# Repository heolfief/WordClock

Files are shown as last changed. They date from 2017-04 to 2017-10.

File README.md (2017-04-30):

# 8x8 Dot Matrix Word Clock
This is an AVR based mini word clock featuring:
* Real Time Clock (DS3231)
* LiPo battery with integrated USB charging circuit
* low battery sensing

The unit is composed of two stacked PCB and one 8x8 dot-matrix display module.

The Hardware folder is composed of Autodesk Eagle CAD files (schematics and PCB) and of Bill Of Materials.

The Software folder is composed of Atmel Studio 7.0 project files, including libraries and hex file.

The I2C-master-lib is from user g4lvanix on Github ([github.com/g4lvanix/I2C-master-lib](http://github.com/g4lvanix/I2C-master-lib)). However, he does not include any licence in his repository therefore all rights for this library belongs to him.
All other libraries included are under the licence descibed in the LICENCE.md file.

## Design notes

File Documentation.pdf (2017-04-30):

2017

# 8X8 DOT MATRIX WORD CLOCK

### This is an AVR based mini word clock featuring: - Real Time Clock (DS3231) - LiPo battery with integrated USB charging circuit (MCP73831) - low battery sensing

The unit is composed of two stacked PCB and one 8x8 dot-matrix display module.

# Heol Fief

github.com/heolfief

Heol Fief
github.com/heolfief | 1

## Table of Contents

## 1. 8x8 Dot matrix letters and MCU PORTs configuration

## a. Letters display configuration

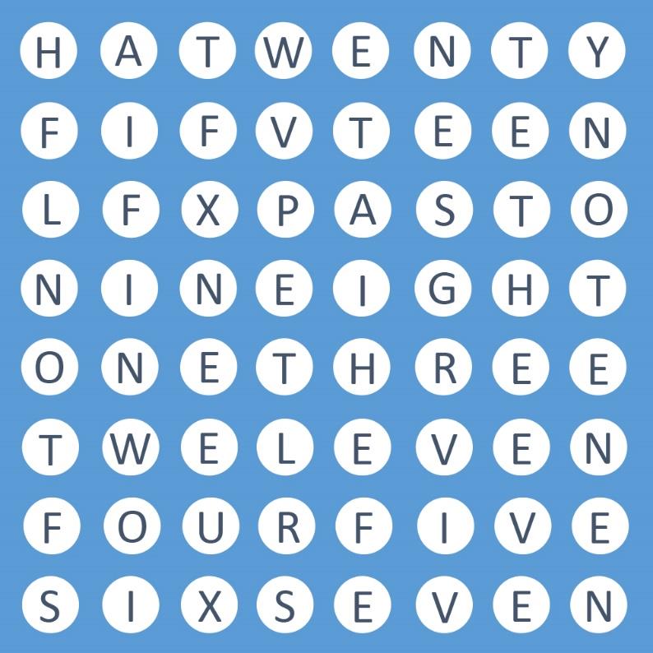
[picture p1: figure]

Figure 1 is the matrix configuration for displaying time in the following format:

Minutes | Link | Hours
| PAST | ONE
FIVE | TO | TWO
TEN | | THREE
FIFTEEN | | FOUR
TWENTY | | FIVE
TWENTY FIVE | | SIX
HALF | | SEVEN
EIGHT
NINE
TEN
ELEVEN
TWELVE

e.g.: HALF PAST TEN (10:30) or TEN TO THREE (02:50).

Note that a.m. and p.m. are considered the same.

FIGURE 1: LETTERS CONFIGURATION

## b. LED matrix pinout

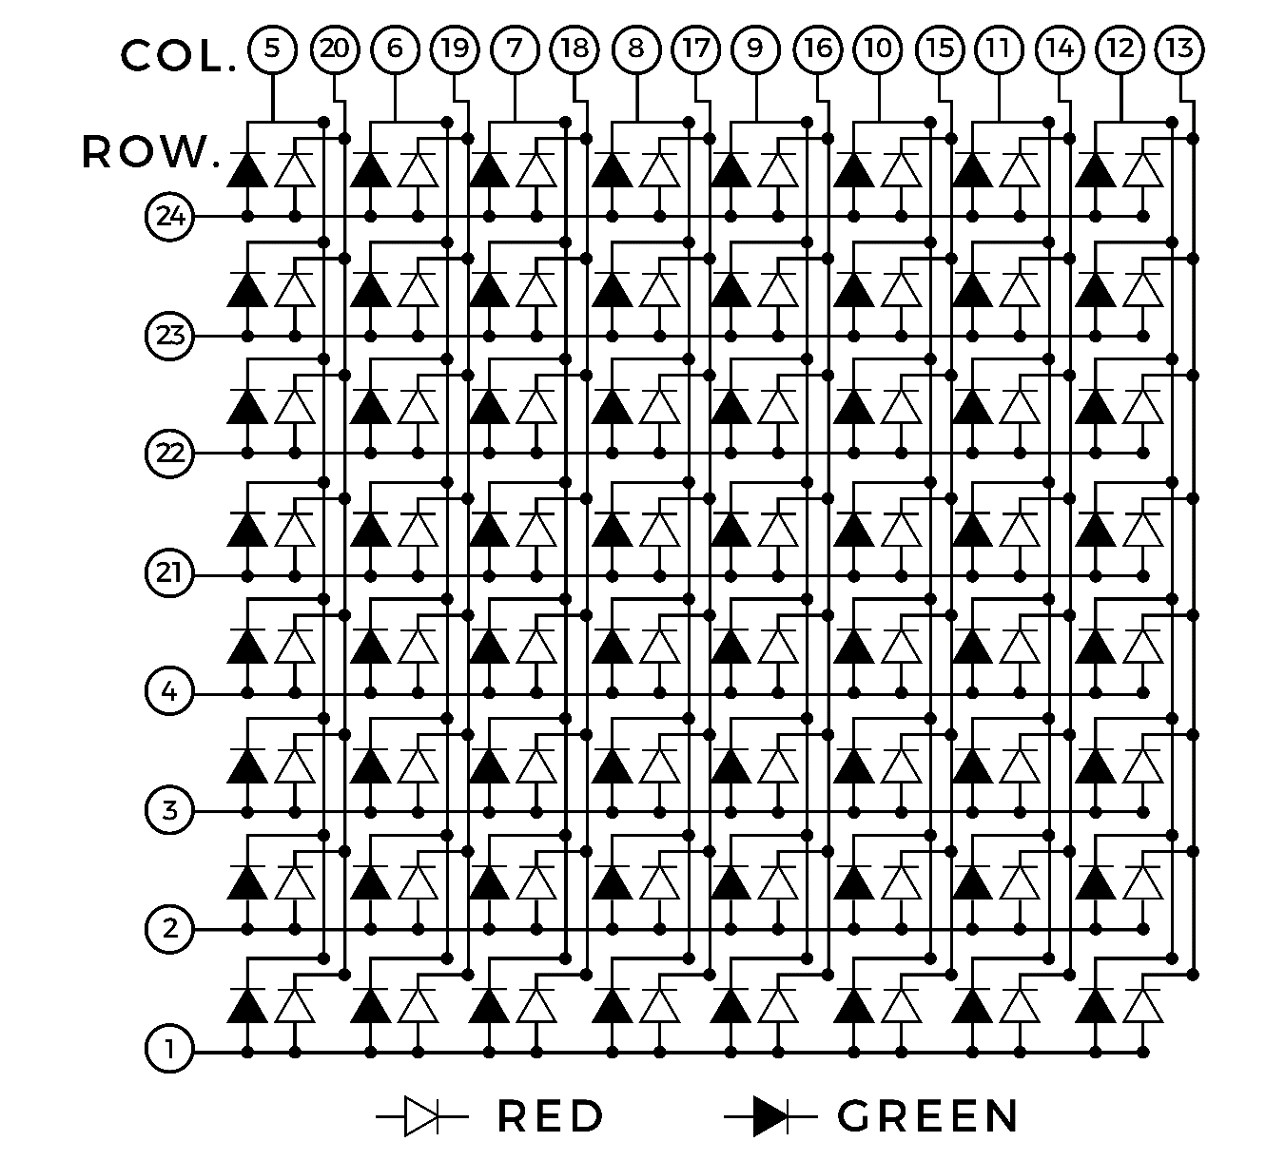
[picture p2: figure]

This is the pinout diagram of the “1588ABEG-5” 8x8 dot matrix display.
In this design, only the green LED are used. Therefore, red LED cathodes (pins 20, 19, 18, 17, 16, 15, 14 and 13) are connected to VCC (LEDs off).

FIGURE 2: LED MATRIX PINOUT

## c. MCU ports configuration

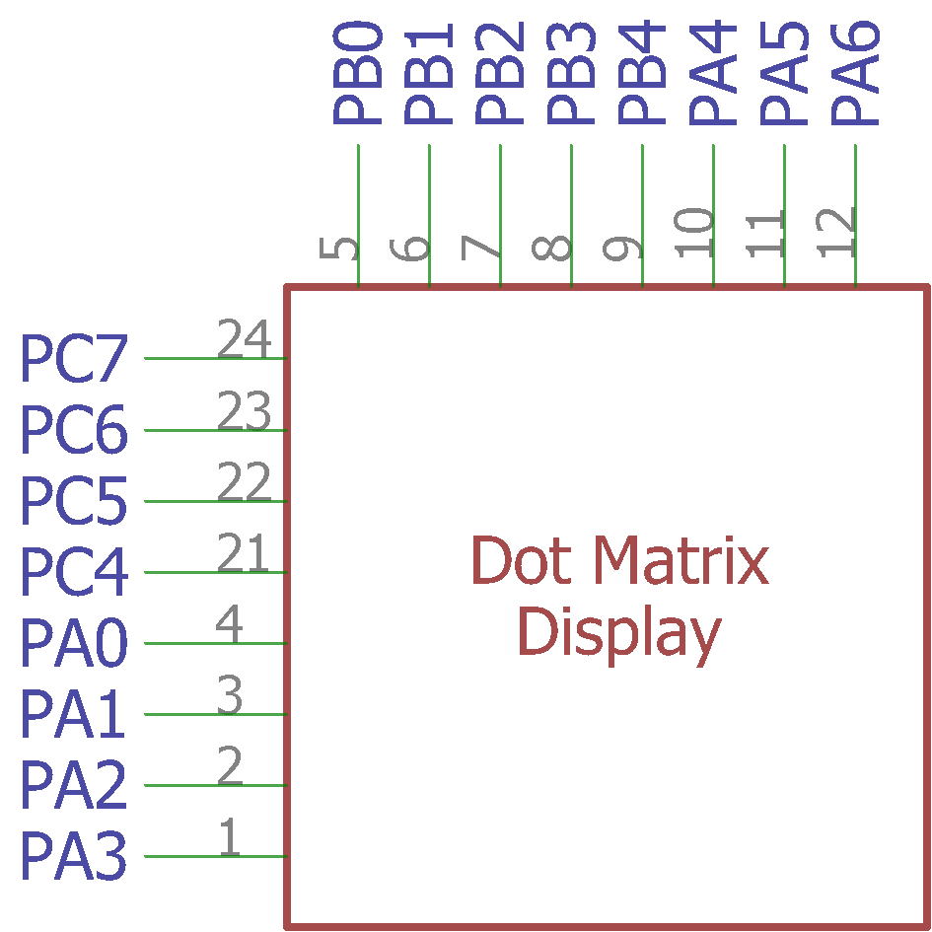
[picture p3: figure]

: Matrix pinout

: MCU pinout

Figure 3 is the connection diagram between the AVR pins and the Matrix pins. ‘PXy’ stands for PORTX pin y.

FIGURE 3: MCU TO MATRIX CONNECTIONS

## 2. Battery voltage sensing calculations

## a. Voltage divider:

LiPo battery voltage needs to be stepped down from 4.3v (maximum value) to 3.3v to be read properly by the MCU running at 3.3v.

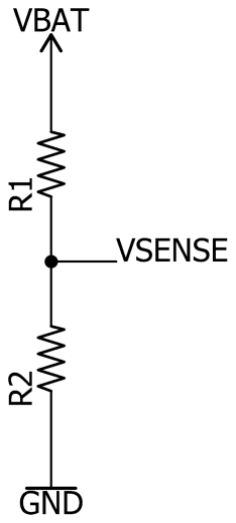
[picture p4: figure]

Vsense =

R2
R1+R2

Vbat

⇔ R2 = −

Vsense

Vsense+Vbat

R1

⇔ R2 = −

3.3
3.3+4.3

R1
⇔ R2 = 3.3R1

For R₁ = 100kΩ, R₂ =330kΩ.

By choosing such high resistor values, we limit the current going from Vbat to GND, lim-iting battery discharge.

Here, Iwasted =

Vbat
R1+R2

=

3.7
430

k = 8.6µA which won't discharge the battery too quickly.

By taking the formula in reverse, we get: Vsense = 330 k 330k+100k
Vbat =

33
43

Vbatwhich

means for example if the MCU mesures 2.5v, the battery voltage Vbat equals 2.5

33
43

⁄ = 2.5

43
33

= 3.26v.

## a. Sensing voltage:

The ATmega32A has a 10 bit DAC which means it can measure voltages from GND (0v) to AREF (3,3v in this case), with a 10 bits resolution (0 to 1023).

To get the battery voltage from the 10 bit number returned by the ADC conversion, we need to apply this formula: Vbat =

3.3ADCvalue
1023

×

43
33

In C, it is done by executing this line of code: float voltage = adcvalue*3.3*43/1023/33;

FIGURE 4: BATTERY
SENSING VOLTAGE
DIVIDER

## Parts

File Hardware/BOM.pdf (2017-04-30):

Word Clock BOM

Part | Value | Description | Package
IC1 | ATMEGA32-A | MICROCONTROLLER | TQFP44
IC2 | HT7333 | Low Dropout voltage regulator 3.3v | SOT-89
IC3 | DS3231 | Real Time Clock | SOIC-16W
IC4 | MCP73831 | MCP73831T Li-Ion, Li-Po Controller | SOT23-5
R1, R10 | 10k | Resistor | 0805
R2, R7 | 330 | Resistor | 0805
R3 | 2k | Resistor | 0805
R4 | 100k | Resistor | 0805
R5 | 330k | Resistor | 0805
R6 | 390 | Resistor | 0805
R8, R9 | 4,7k | Resistor | 0805
RN1, RN2 | 390 | Array Chip Resistor | 0603-ARC
C1, C2, C4, C7, C8 | 0.1u | Capacitor | 0805
C3 | 47u | Tantalum Capacitor | D / 7343
C5, C6 | 4.7u | Capacitor | 0805
LED1 | Green | LED | 1206
LED2 | Red | LED | 1206
LED3 | 1588ABEG-5_8X8-LED_MATRIX | 8x8 dot matrix display, green and red | 1588ABEG-5
J1 | LiPo battery connector | 0.1 inch spaced header connections | MOLEX-1X2
J2, J3, J4, J6, J7, J8 | | 0.1 inch spaced header connections | 1X02
J5, J9 | | 0.1 inch spaced header connection | 1X01
J10 | USB MICRO B | USB connector SMD package | USB-MICRO B
| | | SMD
JP1 | 6 pin AVR ICSP right angle connector | 0.1 inch spaced header connections | 2X03 /90°
S1 | Momentary button 6.mm THT | Momentary Switch (Pushbutton) - SPST | 6.0MM

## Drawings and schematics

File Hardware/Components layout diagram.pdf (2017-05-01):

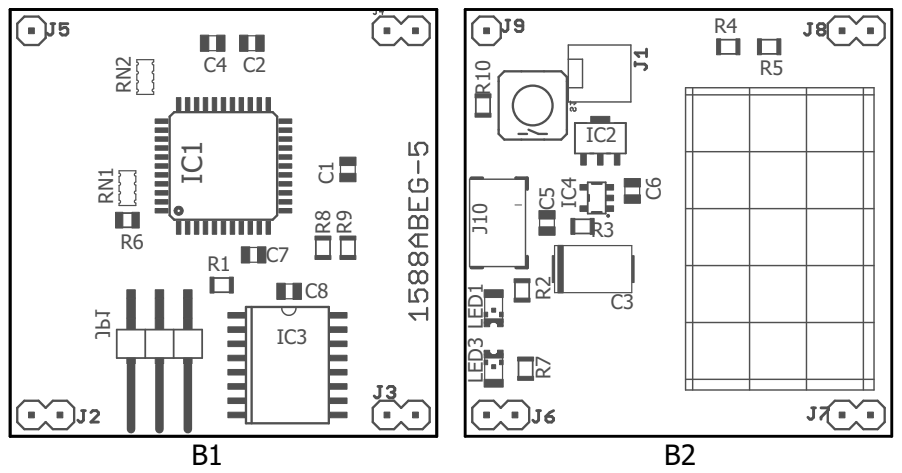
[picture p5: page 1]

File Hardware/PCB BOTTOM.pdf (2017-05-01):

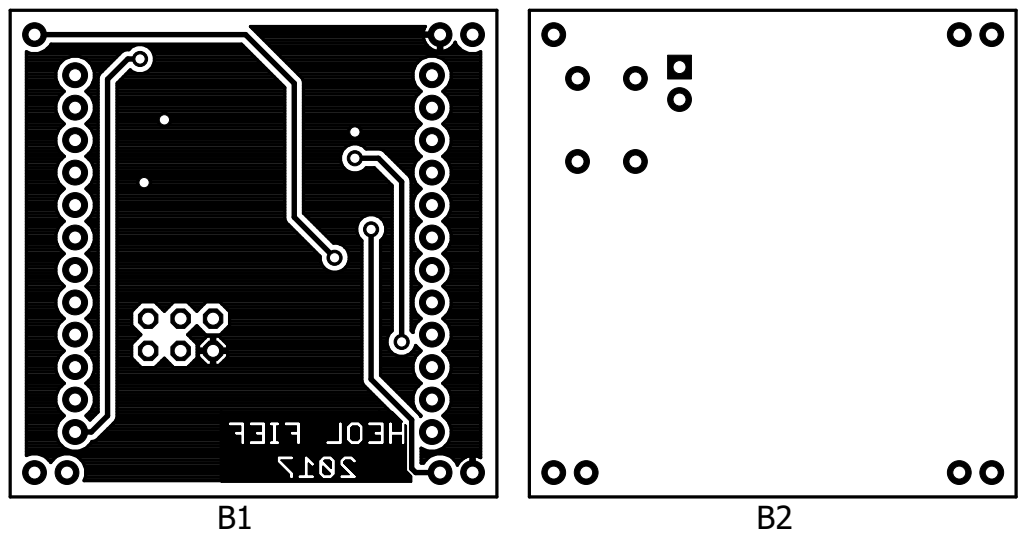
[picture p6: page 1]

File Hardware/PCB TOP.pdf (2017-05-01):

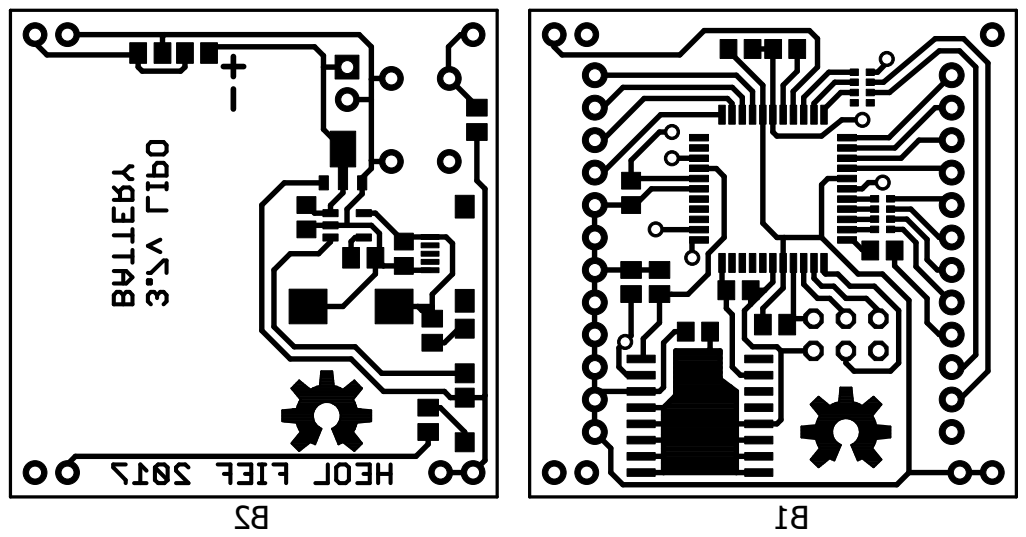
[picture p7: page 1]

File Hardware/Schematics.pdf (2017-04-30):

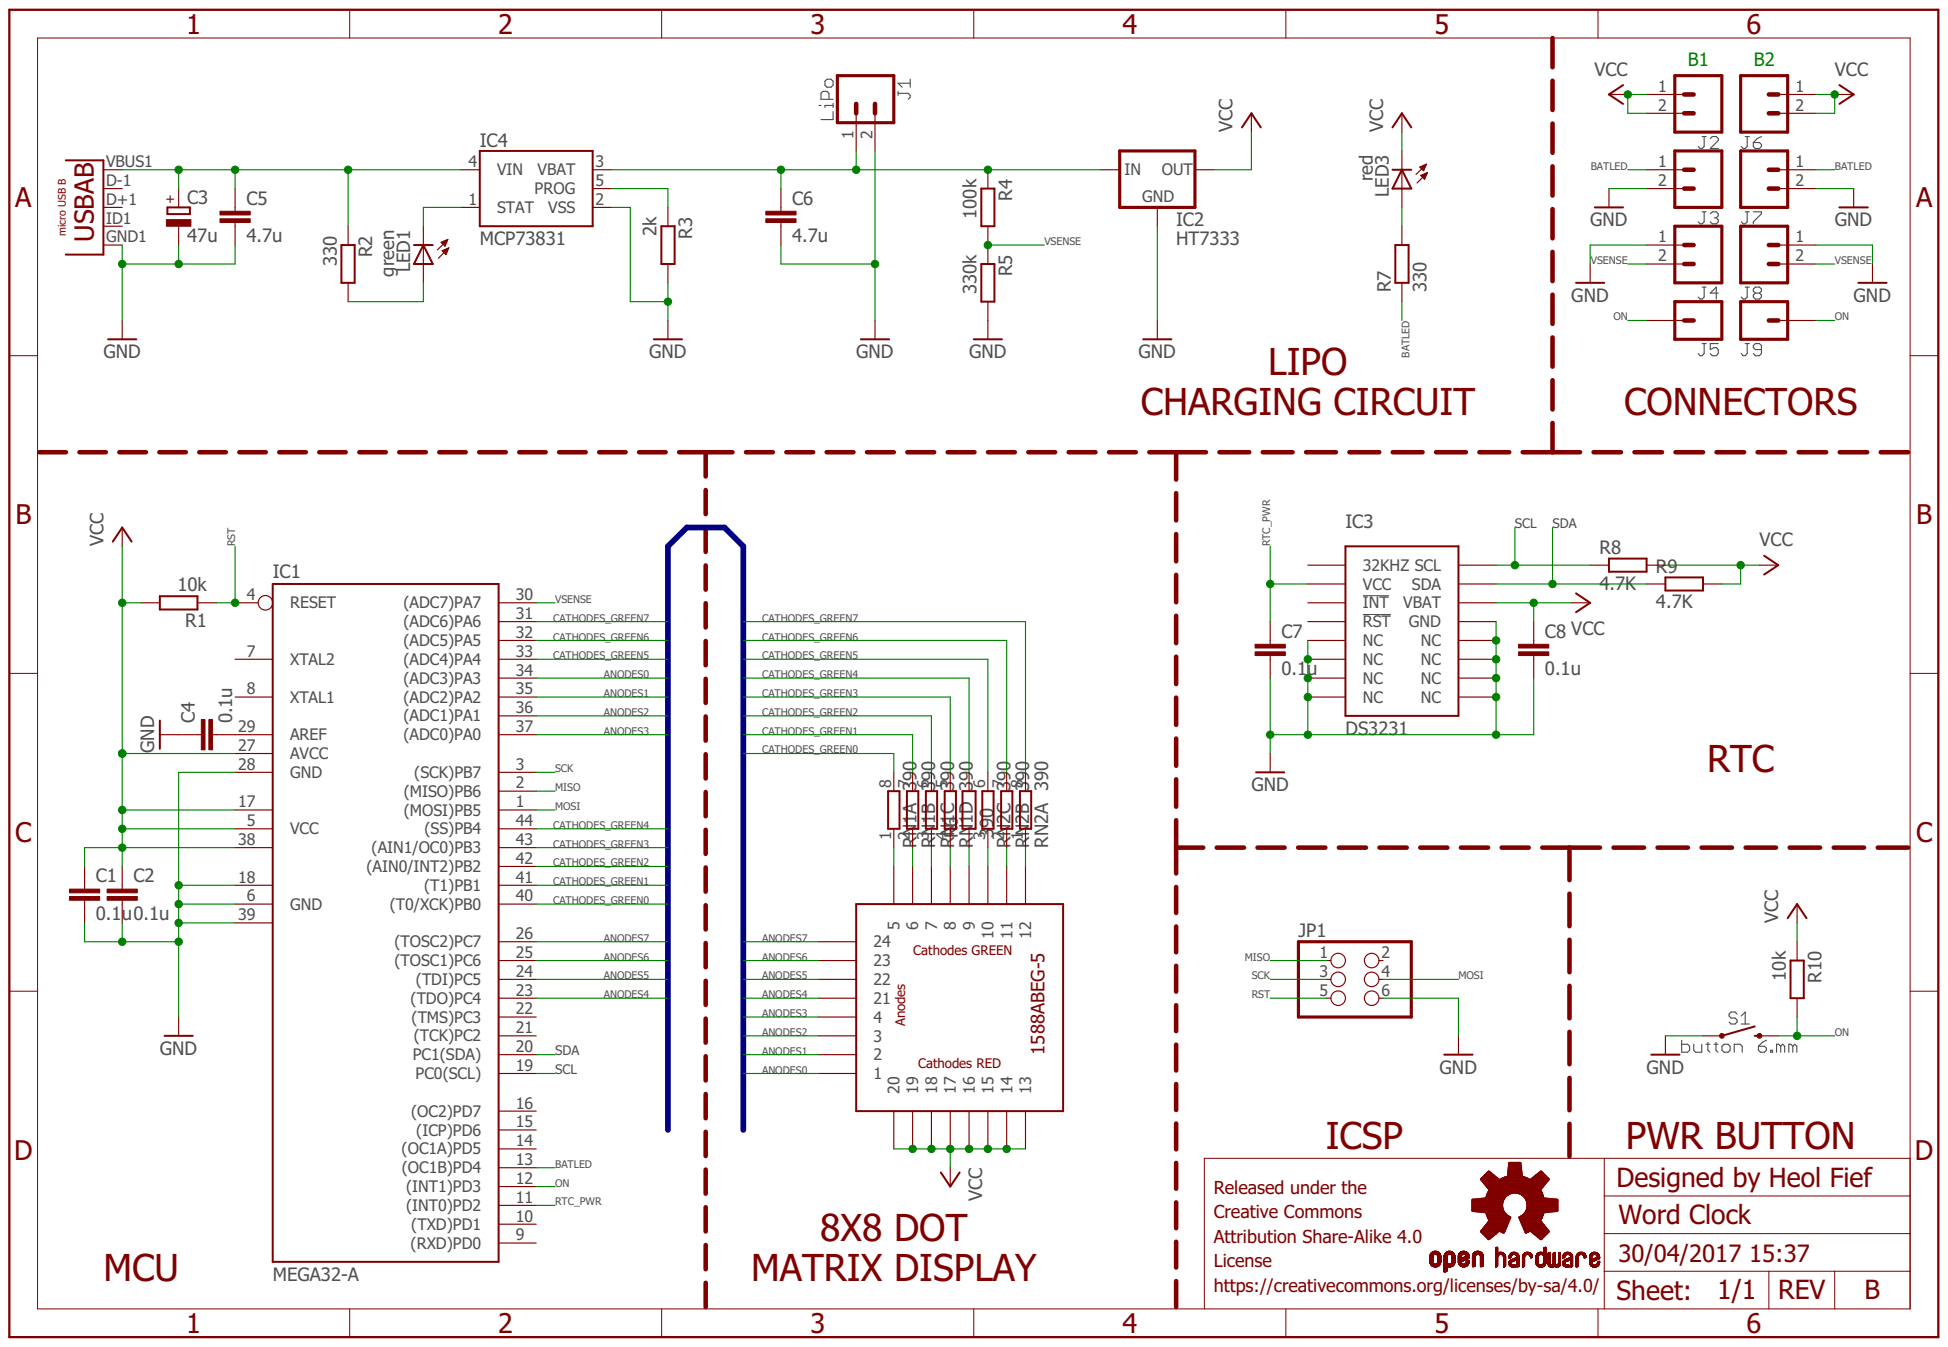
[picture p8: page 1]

Designed by Heol Fief Released under the Creative Commons Attribution Share-Alike 4.0

License https://creativecommons.org/licenses/by-sa/4.0/

Sheet: 1/1 | REV | B

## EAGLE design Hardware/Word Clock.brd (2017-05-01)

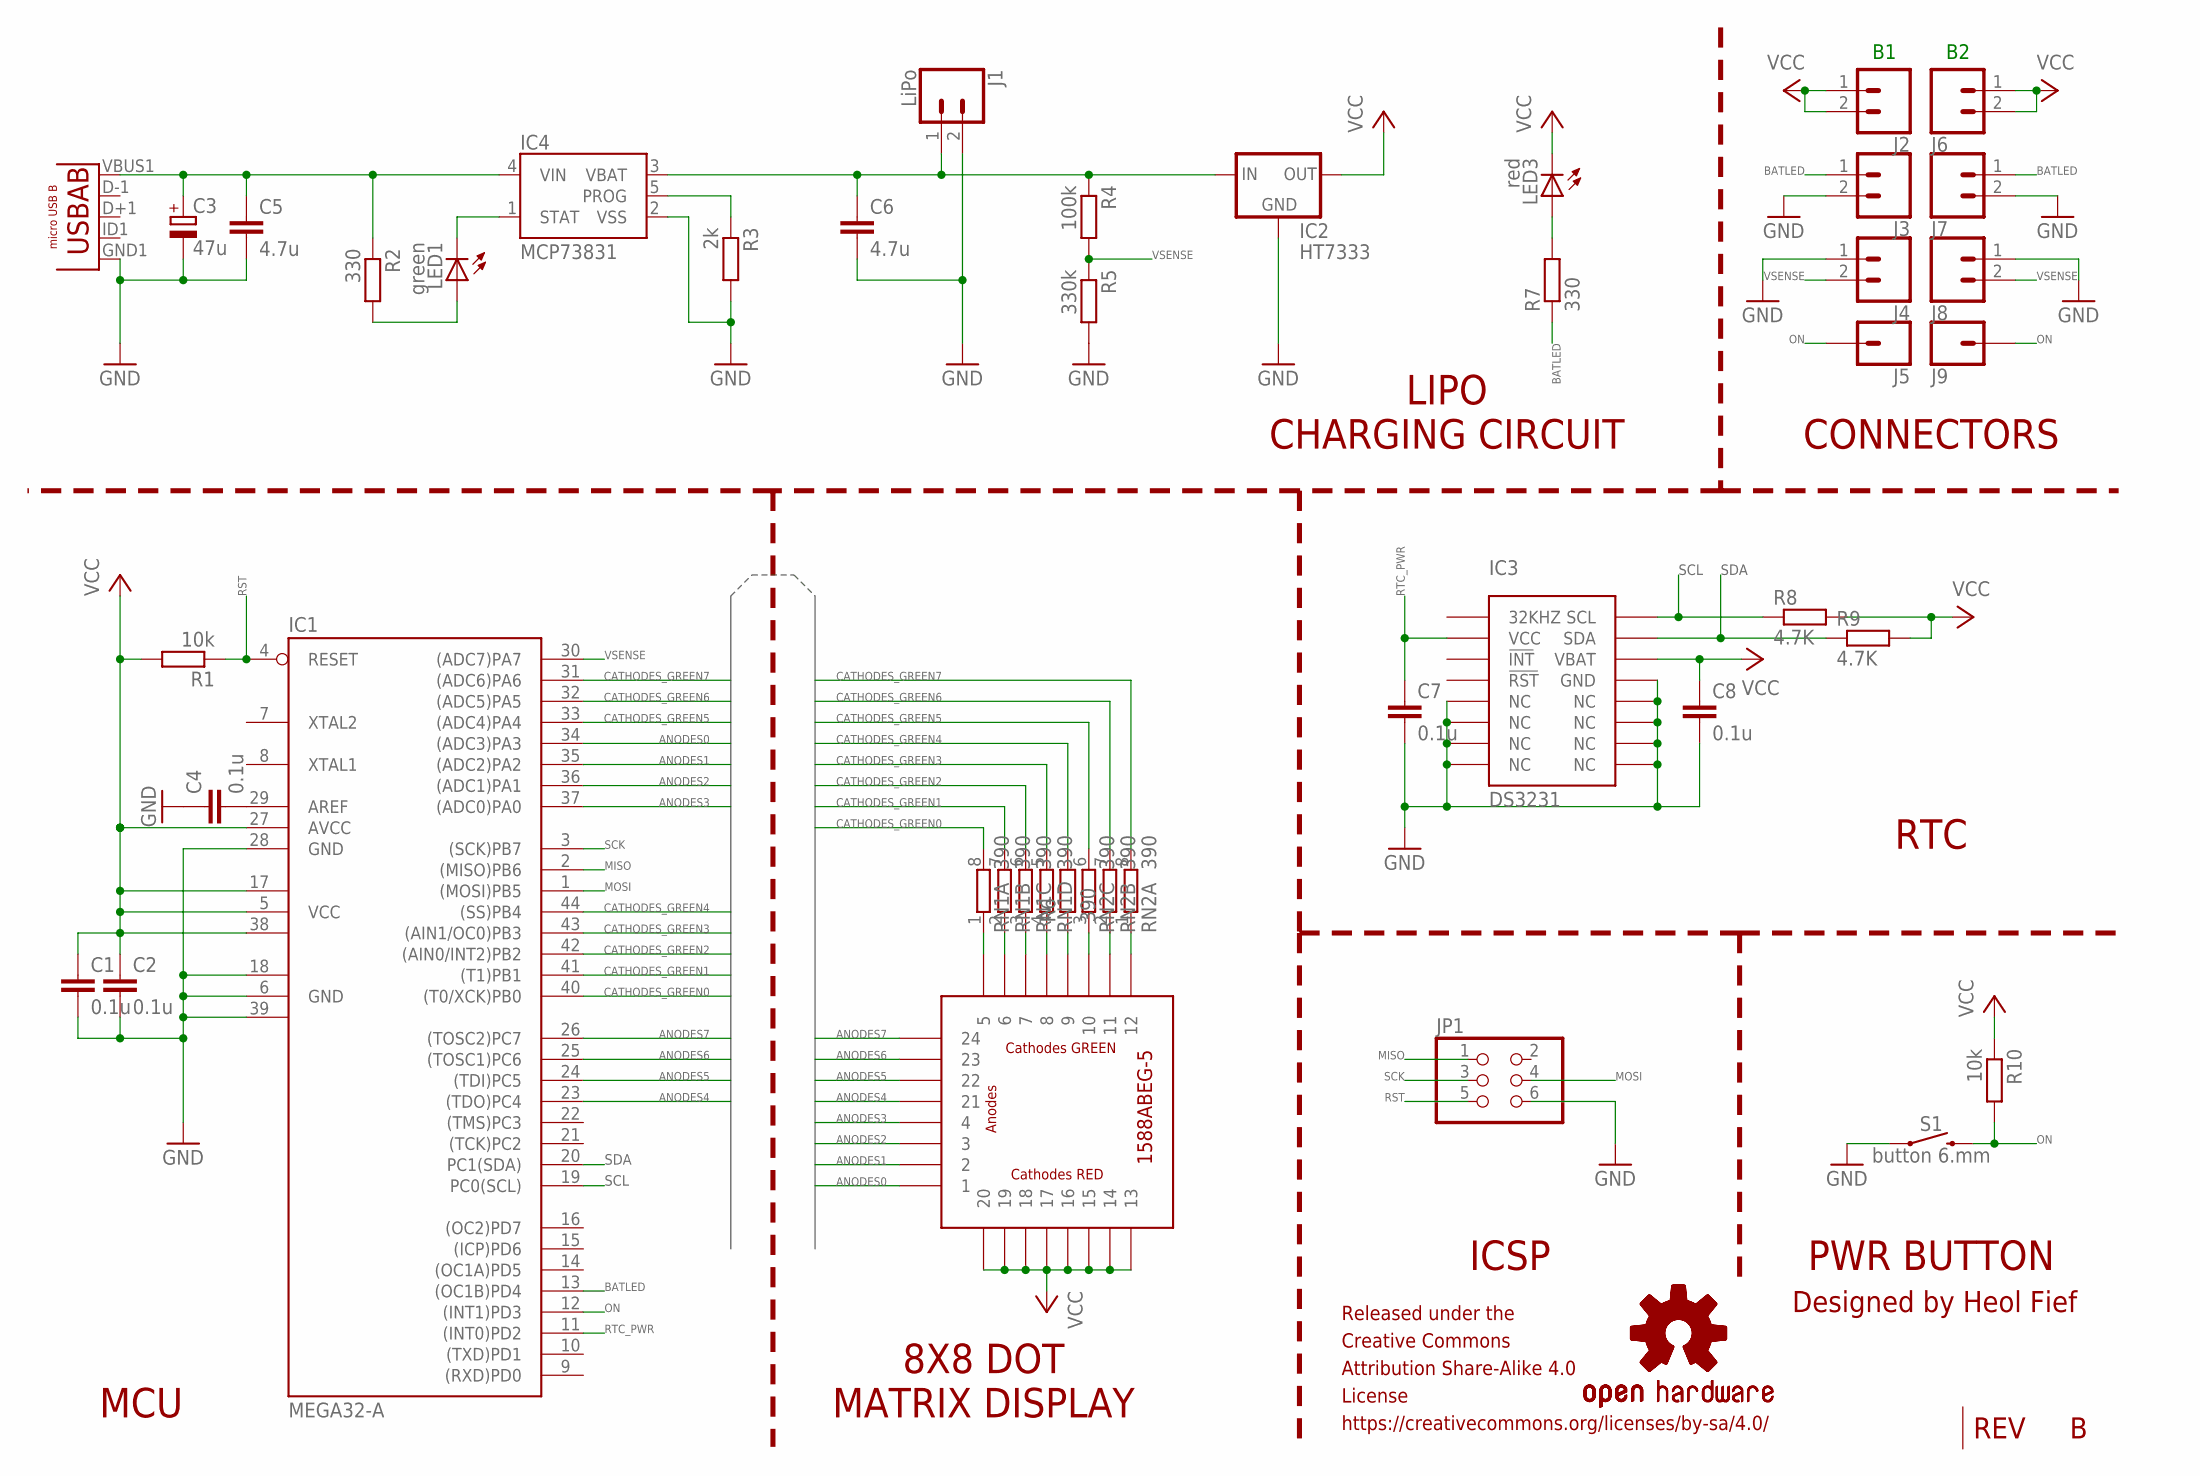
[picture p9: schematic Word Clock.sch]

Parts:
C1, C2, C4, C7, C8: 0.1u; C0805
C3: 47u; D/7343-31W
C5, C6: 4.7u; C0805
IC1: MEGA32-A; TQFP44
IC2: HT7333; SOT-89
IC3: DS3231; SOIC-16W
IC4: MCP73831; SOT23-5
J1: LiPo; MOLEX-1X2
J2, J3, J4, J6, J7, J8: CONN_02; 1X02
J5, J9: CONN_01; 1X01
J10: USB""; USB-MICRO-SMD
JP1: PINHD-2X3/90; 2X03/90
LED1: green; CHIPLED_1206
LED2: 1588ABEG-5_8X8-LED_MATRIX
LED3: red; CHIPLED_1206
LOGO1, LOGO2: OSHW-LOGOL-COPPER; OSHW-LOGO-L_COPPER
R1, R10: 10k; M0805
R2, R7: 330; M0805
R3: 2k; M0805
R4: 100k; M0805
R5: 330k; M0805
R6: 390; R0805
R8, R9: 4.7K; M0805
RN1, RN2: 390; 0603-ARC
S1: button 6.mm; TACTILE_SWITCH_PTH_6.0MM

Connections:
ANODES0: IC1.34 ((ADC3)PA3), LED2.P$1 (1)
ANODES1: IC1.35 ((ADC2)PA2), LED2.P$2 (2)
ANODES2: IC1.36 ((ADC1)PA1), LED2.P$3 (3)
ANODES3: IC1.37 ((ADC0)PA0), LED2.P$4 (4)
ANODES4: IC1.23 ((TDO)PC4), LED2.P$21 (21)
ANODES5: IC1.24 ((TDI)PC5), LED2.P$22 (22)
ANODES6: IC1.25 ((TOSC1)PC6), LED2.P$23 (23)
ANODES7: IC1.26 ((TOSC2)PC7), LED2.P$24 (24)
AREF: C4.2, IC1.29 (AREF)
BATLED: IC1.13 ((OC1B)PD4), J3.1, J7.1, R7.1
CATHODES_GREEN0: IC1.40 ((T0/XCK)PB0), RN1.8 (2)
CATHODES_GREEN1: IC1.41 ((T1)PB1), RN1.7 (2)
CATHODES_GREEN2: IC1.42 ((AIN0/INT2)PB2), RN1.6 (2)
CATHODES_GREEN3: IC1.43 ((AIN1/OC0)PB3), RN1.5 (2)
CATHODES_GREEN4: IC1.44 ((SS)PB4), R6.2
CATHODES_GREEN5: IC1.33 ((ADC4)PA4), RN2.6 (2)
CATHODES_GREEN6: IC1.32 ((ADC5)PA5), RN2.7 (2)
CATHODES_GREEN7: IC1.31 ((ADC6)PA6), RN2.8 (2)
GND: C1.2, C2.2, C3.-, C4.1, C5.2, C6.2, C7.2, C8.2, IC1.6 (GND), IC1.18 (GND1), IC1.28 (GND), IC1.39 (GND2), IC2.2 (GND), IC3.5 (NC), IC3.6 (NC), IC3.7 (NC), IC3.8 (NC), IC3.9 (NC), IC3.10 (NC), IC3.11 (NC), IC3.12 (NC), IC3.13 (GND), IC4.2 (VSS), J1.2, J3.2, J4.1, J7.2, J8.1, J10.GND1 (GND), JP1.6, R3.2, R5.2, S1.1, S1.2 (1)
MISO: IC1.2 ((MISO)PB6), JP1.1
MOSI: IC1.1 ((MOSI)PB5), JP1.4
unnamed: LED2.P$5 (5), RN1.1
unnamed: IC4.5 (PROG), R3.1
unnamed: LED2.P$6 (6), RN1.2 (1)
unnamed: LED2.P$7 (7), RN1.3 (1)
unnamed: C6.1, IC2.3 (IN), IC2.4 (IN), IC4.3 (VBAT), J1.1, R4.1
unnamed: LED2.P$8 (8), RN1.4 (1)
unnamed: LED1.A, R2.2
unnamed: IC4.1 (STAT), LED1.C
unnamed: C3.+, C5.1, IC4.4 (VIN), J10.VBUS1 (VBUS), R2.1
unnamed: LED2.P$9 (9), R6.1
unnamed: LED2.P$10 (10), RN2.3 (1)
unnamed: LED2.P$11 (11), RN2.2 (1)
unnamed: LED2.P$12 (12), RN2.1
unnamed: LED3.A, R7.2
ON: IC1.12 ((INT1)PD3), J5.1, J9.1, R10.2, S1.3 (2), S1.4 (2)
RST: IC1.4 (RESET), JP1.5, R1.1
RTC_PWR: C7.1, IC1.11 ((INT0)PD2), IC3.2 (VCC)
SCK: IC1.3 ((SCK)PB7), JP1.3
SCL: IC1.19 (PC0(SCL)), IC3.16 (SCL), R8.1
SDA: IC1.20 (PC1(SDA)), IC3.15 (SDA), R9.1
VCC: C1.1, C2.1, C8.1, IC1.5 (VCC), IC1.17 (VCC1), IC1.27 (AVCC), IC1.38 (VCC2), IC2.1 (OUT), IC3.14 (VBAT), J2.1, J2.2, J6.1, J6.2, LED2.P$13 (13), LED2.P$14 (14), LED2.P$15 (15), LED2.P$16 (16), LED2.P$17 (17), LED2.P$18 (18), LED2.P$19 (19), LED2.P$20 (20), LED3.C, R1.2, R8.2, R9.2, R10.1
VSENSE: IC1.30 ((ADC7)PA7), J4.2, J8.2, R4.2, R5.1

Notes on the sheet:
MCU
8X8 DOT MATRIX DISPLAY
PWR BUTTON
RTC
ICSP
LIPO CHARGING CIRCUIT
CONNECTORS
REV
Designed by Heol Fief
Released under the Creative Commons Attribution Share-Alike 4.0 License https://creativecommons.org/licenses/by-sa/4.0/
micro USB B

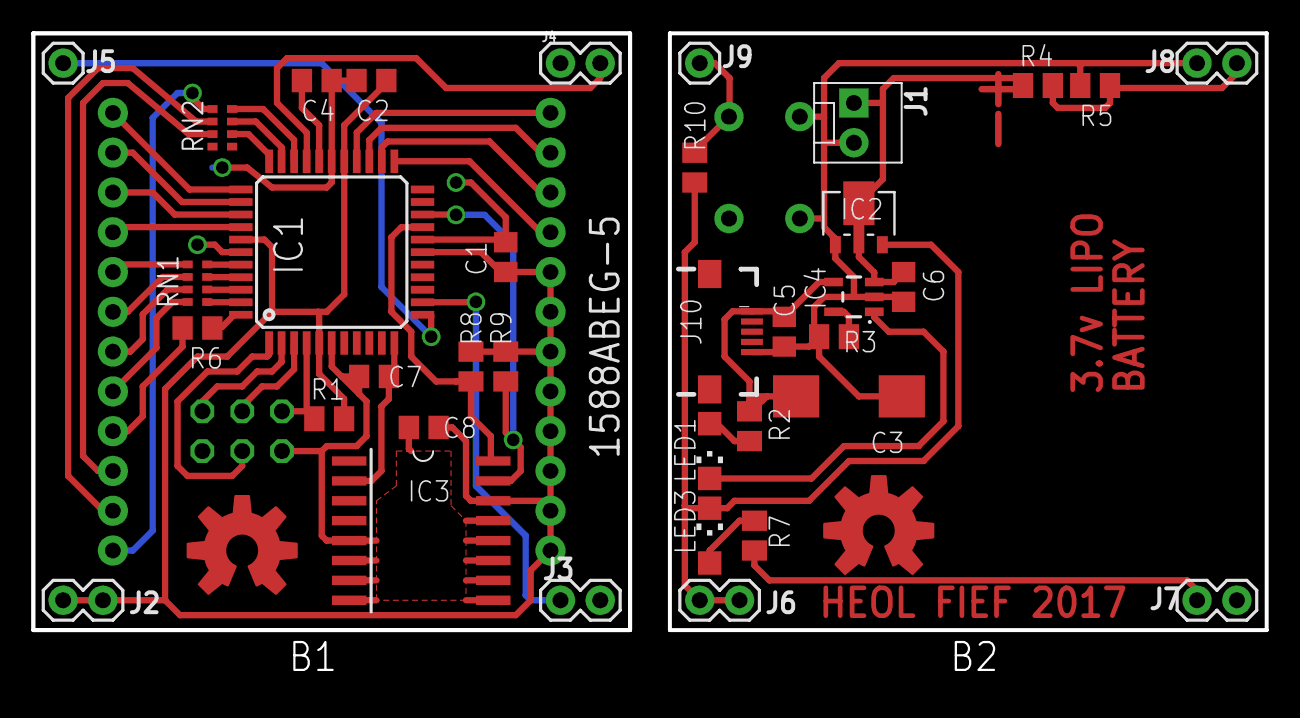
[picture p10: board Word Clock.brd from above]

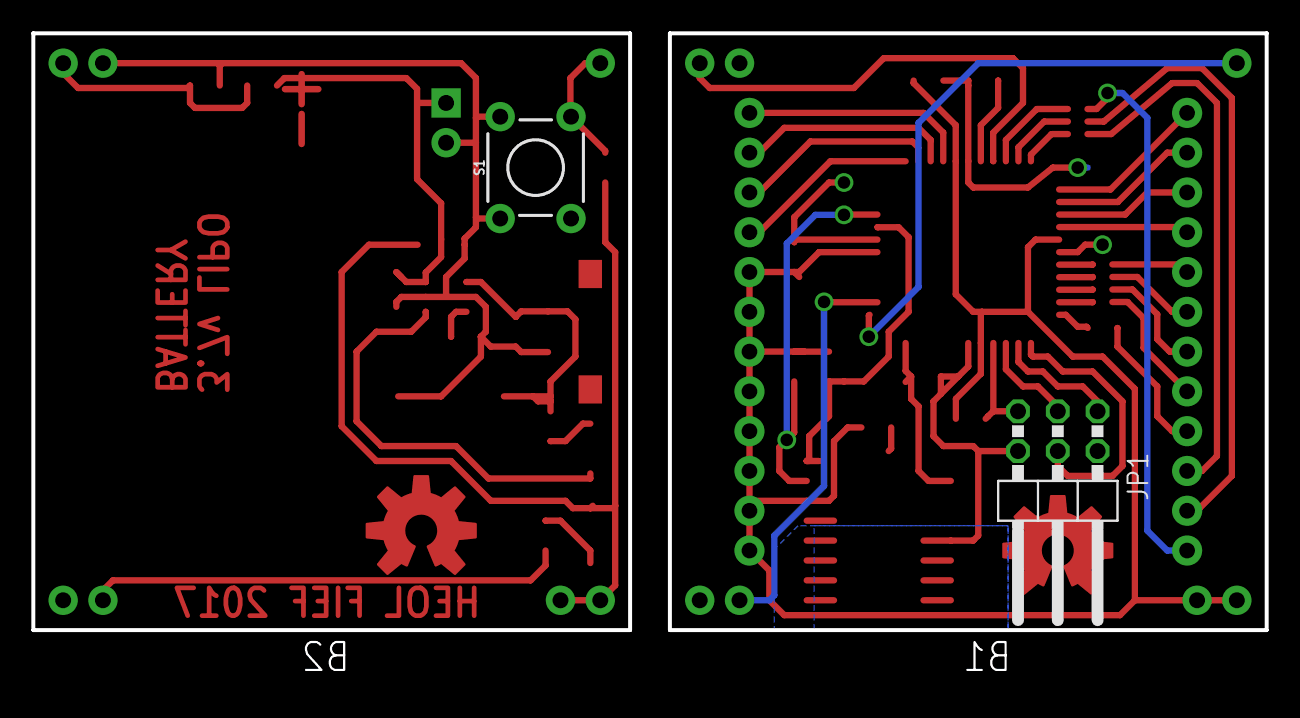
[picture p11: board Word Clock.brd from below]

Board: 2 copper layers, 78.7 x 38.1 mm, 41 parts (2 on the bottom side), 43 nets.

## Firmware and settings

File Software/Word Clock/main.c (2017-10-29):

/*
*
*		OUTPUT PINS CONFIGURATION AND 8X8 MATRIX LETTERS CONFGURATION
*
*
*	PORTS	PB0		PB1		PB2		PB3		PB4		PA4		PA5		PA6
*	PORTS	___		___		___		___		___		___		___		___
*
*	PC7	|	 H		 A		 T		 W		 E		 N		 T		 Y
*
*
*	PC6	|	 F		 I		 F		 V		 T		 E		 E		 N
*
*
*	PC5	|	 L		 F		 X		 P		 A		 S		 T		 O
*
*
*	PC4	|	 N		 I		 N		 E		 I		 G		 H		 T
*
*
*	PA0	|	 O		 N		 E		 T		 H		 R		 E		 E
*
*
*	PA1	|	 T		 W		 E		 L		 E		 V		 E		 N
*
*
*	PA2	|	 F		 O		 U		 R		 F		 I		 V		 E
*
*
*	PA3	|	 S		 I		 X		 S		 E		 V		 E		 N
*
*/


#define V_LOWBAT 3.4							// Low battery voltage value
#define V_CRITBAT 3.3 							// Critical battery voltage value



#define F_CPU 1000000UL  						// MCU is running at 1MHz

// Include needed libraries
#include <stdio.h>
#include <avr/io.h>
#include <avr/interrupt.h>
#include <avr/sleep.h>
#include <util/delay.h>

#include "lib/rtcDS3231/rtcDS3231.h"			// Include RTC library

// Functions definitions
void minutes_to_matrix(uint8_t now_minutes, uint8_t *line_data);
void hours_to_matrix(uint8_t now_hours, uint8_t *line_data);
void display(uint8_t *line_data, uint16_t number_of_loops);
void sleep();
void io_setup();
void check_battery(uint8_t *lowbat, uint8_t *critbat);

// Global variables
uint8_t setmode=0;								// ...
uint8_t time_counter=0;							// ...
uint8_t bt_flag=0;								// ...To be used by the ISR

// Main program
int main()
{
	uint8_t hour, min, sec, am_pm, data[8]={0}, low_battery=0, critical_battery=0, i;	// 8 bits variables declaration

	io_setup();									// Configure the MCU's GPIO
	
	PORTD |= (1<<PD2);							// Give power to RTC
	i2c_init();									// Initialize I2C communication
	PORTD &= ~(1<<PD2);							// Cut power to RTC	
		
	while (1)
	{
		sleep();
		
		check_battery(&low_battery, &critical_battery);
		
		if(low_battery) PORTD &= ~(1<<PD4);		// if battery level is low, turn ON a LED and run the program
		
		if(critical_battery)					// if battery level is critical, blink a LED ON and OFF and don't run the program
		{
			for(i=0; i<10; i++)					// Number of LED blinks
			{
				PORTD ^= (1<<PD4);				// Invert output state of PD4 (connected to LED cathode)
				_delay_ms(250);					// Wait 250ms
			}
			PORTD |= (1<<PD4);					// Turn OFF LED (output 5v to LED cathode)
		}
		else									// If battery level is good
		{
			PORTD |= (1<<PD2);					// Give power to RTC
			i2c_init();							// Initialize I2C communication
			rtc_get_time_12h(&hour, &min, &sec, &am_pm);	// Get time
			PORTD &= ~(1<<PD2);					// Cut power to RTC
			
			minutes_to_matrix(min, data);		// Convert minutes to the data array to be displayed on the LED matrix
			if(min>35)hour++;					// If minutes are more than half an hour, then add an hour to the display
			hours_to_matrix(hour, data);		// Convert hours to the data array to be displayed on the LED matrix
			display(data, 1000);					// Display the data array for 10s (1251)
			
			if (bit_is_clear(PIND,PD3))			// If button is still pressed
			{
				MCUCR |= (1<<ISC11);			// ...
				MCUCR &= ~(1<<ISC10);			// ... Enable interrupt on falling edge of INT1
				sei();                         	// Enable interrupts
				setmode=1;						// Go to setmode
				
				for (time_counter=0;time_counter<20;time_counter++) // Blink several times
				{
					if (bt_flag)
					{
						bt_flag=0;				// Reset button flag
						min=min-min%5;			// Set min to nearest 5min step
						min+=5;					// Increase minutes by 5 on button press
						if (min>=60)min=0;		// Handle minutes overflow
						if ((min>=35) && (min<40))hour++; // Increase hour
						if (hour>=12)hour=0;	// Handle hour overflow
					}
					minutes_to_matrix(min, data);	// Convert minutes to the data array to be displayed on the LED matrix
					hours_to_matrix(hour, data);// Convert hours to the data array to be displayed on the LED matrix
					display(data, 31);			// Display the data array for 0.25s
					_delay_ms(50);				// Wait 250ms
				}
				cli();                         	// Disable interrupts
				setmode=0;						// Exit setmode
				
				PORTD |= (1<<PD2);				// Give power to RTC
				rtc_set_time_12h(hour,min,0,0);	// Set new time to RTC
				PORTD &= ~(1<<PD2);				// Cut power to RTC
			}
		}
	}
}

void minutes_to_matrix(uint8_t now_minutes, uint8_t *line_data)
{
	switch(now_minutes)
	{
		// Each bit correspond to the letter above him. LED matrix is active low, 0 is LED ON, 1 is LED OFF
		
		// minutes from 0 to 4 : line 0,1 and 2 OFF						   HATWENTY					  FIFVTEEN					 LFXPASTO
	case  0 : case  1 : case  2 : case  3 : case  4 : line_data[0] = 0b11111111; line_data[1] = 0b11111111; line_data[2] = 0b11111111; break;
		
		// minutes from 5 to 9 : "five" and "past" words are lit		   HATWENTY					  FIFVTEEN					 LFXPASTO
	case  5 : case  6 : case  7 : case  8 : case  9 : line_data[0] = 0b11111111; line_data[1] = 0b00101011; line_data[2] = 0b11100001; break;
		
		// minutes from 10 to 14 : "ten" and "past" words are lit		   HATWENTY					  FIFVTEEN					 LFXPASTO
	case 10 : case 11 : case 12 : case 13 : case 14 : line_data[0] = 0b11010011; line_data[1] = 0b11111111; line_data[2] = 0b11100001; break;
		
		// minutes from 15 to 19 : "fifteen" and "past" words are lit	   HATWENTY					  FIFVTEEN					 LFXPASTO
	case 15 : case 16 : case 17 : case 18 : case 19 : line_data[0] = 0b11111111; line_data[1] = 0b00010000; line_data[2] = 0b11100001; break;
		
		// minutes from 20 to 24 : "twenty" and "past" words are lit	   HATWENTY					  FIFVTEEN					 LFXPASTO
	case 20 : case 21 : case 22 : case 23 : case 24 : line_data[0] = 0b11000000; line_data[1] = 0b11111111; line_data[2] = 0b11100001; break;
		
		// minutes from 25 to 29 : "twenty five" and "past" words are lit  HATWENTY					  FIFVTEEN					 LFXPASTO
	case 25 : case 26 : case 27 : case 28 : case 29 : line_data[0] = 0b11000000; line_data[1] = 0b00101011; line_data[2] = 0b11100001; break;
		
		// minutes from 30 to 34 : "half" and "past" words are lit		   HATWENTY					  FIFVTEEN					 LFXPASTO
	case 30 : case 31 : case 32 : case 33 : case 34 : line_data[0] = 0b00111111; line_data[1] = 0b11111111; line_data[2] = 0b00100001; break;
		
		// minutes from 35 to 39 : "twenty five" and "to" words are lit	   HATWENTY					  FIFVTEEN					 LFXPASTO
	case 35 : case 36 : case 37 : case 38 : case 39 : line_data[0] = 0b11000000; line_data[1] = 0b00101011; line_data[2] = 0b11111100; break;
		
		// minutes from 40 to 44 : "twenty" and "to" words are lit		   HATWENTY					  FIFVTEEN					 LFXPASTO
	case 40 : case 41 : case 42 : case 43 : case 44 : line_data[0] = 0b11000000; line_data[1] = 0b11111111; line_data[2] = 0b11111100; break;
		
		// minutes from 45 to 49 : "fifteen" and "to" words are lit		   HATWENTY					  FIFVTEEN					 LFXPASTO
	case 45 : case 46 : case 47 : case 48 : case 49 : line_data[0] = 0b11111111; line_data[1] = 0b00010000; line_data[2] = 0b11111100; break;
		
		// minutes from 50 to 54 : "ten" and "to" words are lit			   HATWENTY					  FIFVTEEN					 LFXPASTO
	case 50 : case 51 : case 52 : case 53 : case 54 : line_data[0] = 0b11010011; line_data[1] = 0b11111111; line_data[2] = 0b11111100; break;
		
		// minutes from 55 to 59 : "five" and "to" words are lit		   HATWENTY					  FIFVTEEN					 LFXPASTO
	case 55 : case 56 : case 57 : case 58 : case 59 : line_data[0] = 0b11111111; line_data[1] = 0b00101011; line_data[2] = 0b11111100; break;
	}
}

void hours_to_matrix(uint8_t now_hours, uint8_t *line_data)
{
	switch(now_hours)
	{
		// Each bit correspond to the letter above him. LED matrix is active low, 0 is LED ON, 1 is LED OFF
		
		// 	twelve				   NINEIGHT					  ONETHREE					 TWELEVEN					FOURFIVE				   SIXSEVEN
	case  0 : line_data[3] = 0b11111111; line_data[4] = 0b11111111; line_data[5] = 0b00001001; line_data[6] = 0b11111111; line_data[7] = 0b11111111; break;
		
		// 	one					   NINEIGHT					  ONETHREE					 TWELEVEN					FOURFIVE				   SIXSEVEN
	case  1 : line_data[3] = 0b11111111; line_data[4] = 0b00011111; line_data[5] = 0b11111111; line_data[6] = 0b11111111; line_data[7] = 0b11111111; break;
		
		// 	two					   NINEIGHT					  ONETHREE					 TWELEVEN					FOURFIVE				   SIXSEVEN
	case  2 : line_data[3] = 0b11111111; line_data[4] = 0b11111111; line_data[5] = 0b00111111; line_data[6] = 0b10111111; line_data[7] = 0b11111111; break;
		
		// 	three				   NINEIGHT					  ONETHREE					 TWELEVEN					FOURFIVE				   SIXSEVEN
	case  3 : line_data[3] = 0b11111111; line_data[4] = 0b11100000; line_data[5] = 0b11111111; line_data[6] = 0b11111111; line_data[7] = 0b11111111; break;
		
		// 	four				   NINEIGHT					  ONETHREE					 TWELEVEN					FOURFIVE				   SIXSEVEN
	case  4 : line_data[3] = 0b11111111; line_data[4] = 0b11111111; line_data[5] = 0b11111111; line_data[6] = 0b00001111; line_data[7] = 0b11111111; break;
		
		// 	five				   NINEIGHT					  ONETHREE					 TWELEVEN					FOURFIVE				   SIXSEVEN
	case  5 : line_data[3] = 0b11111111; line_data[4] = 0b11111111; line_data[5] = 0b11111111; line_data[6] = 0b11110000; line_data[7] = 0b11111111; break;
		
		// 	six					   NINEIGHT					  ONETHREE					 TWELEVEN					FOURFIVE				   SIXSEVEN
	case  6 : line_data[3] = 0b11111111; line_data[4] = 0b11111111; line_data[5] = 0b11111111; line_data[6] = 0b11111111; line_data[7] = 0b00011111; break;
		
		// 	seven				   NINEIGHT					  ONETHREE					 TWELEVEN					FOURFIVE				   SIXSEVEN
	case  7 : line_data[3] = 0b11111111; line_data[4] = 0b11111111; line_data[5] = 0b11111111; line_data[6] = 0b11111111; line_data[7] = 0b11100000; break;
		
		// 	eight				   NINEIGHT					  ONETHREE					 TWELEVEN					FOURFIVE				   SIXSEVEN
	case  8 : line_data[3] = 0b11100000; line_data[4] = 0b11111111; line_data[5] = 0b11111111; line_data[6] = 0b11111111; line_data[7] = 0b11111111; break;
		
		// 	nine				   NINEIGHT					  ONETHREE					 TWELEVEN					FOURFIVE				   SIXSEVEN
	case  9 : line_data[3] = 0b00001111; line_data[4] = 0b11111111; line_data[5] = 0b11111111; line_data[6] = 0b11111111; line_data[7] = 0b11111111; break;
		
		// 	ten					   NINEIGHT					  ONETHREE					 TWELEVEN					FOURFIVE				   SIXSEVEN
	case 10 : line_data[3] = 0b11111110; line_data[4] = 0b11111110; line_data[5] = 0b11111110; line_data[6] = 0b11111111; line_data[7] = 0b11111111; break;
		
		// 	eleven				   NINEIGHT					  ONETHREE					 TWELEVEN					FOURFIVE				   SIXSEVEN
	case 11 : line_data[3] = 0b11111111; line_data[4] = 0b11111111; line_data[5] = 0b11000000; line_data[6] = 0b11111111; line_data[7] = 0b11111111; break;
	}
}

void display(uint8_t *line_data, uint16_t number_of_loops)
{
	uint8_t i, temp, temprev[8];				// 8 bits variables declaration
	uint16_t y;									// 16 bits variables declaration
	
	for(i=0; i<8; i++)							// For hardware pin mapping reason, reverse each byte of data (8 bytes, 1 byte per line and 1 bit per column )
	{	
		temprev[i] = (line_data[i] * 0x0202020202ULL & 0x010884422010ULL) % 1023;   // Reverse binary (0bABCDEFGH --> 0bHGFEDCBA)
	}
	
	for(y=0; y<number_of_loops; y++)			// Loop multiplexing
	{
		for(i=0; i<8; i++)						// For each line
		{
			temp = temprev[i] & 0b00011111;		// Only the 5 LSB are needed
			PORTB &= 0b11100000;				// Clear the 5 LSB of PORTB
			PORTB |= temp;						// Set the 5 LSB of PORTB to line_data according to schematics
			
			temp = temprev[i]>>5;				// Shift 5 times to the right, to keep only the 3 MSB
			temp = temp<<4;						// Shift 4 times to the left
			PORTA &= 0b10001111;				// Clear the needed bits of PORTA
			PORTA |= temp;						// Set the needed bits of PORTA to line_data according to schematics
			
			switch(i)							// Give power to one line at each time (5v to line number i LED anodes)
			{
			case 0 : PORTC |=  (1<<7); PORTC &= ~(1<<6); PORTC &= ~(1<<5); PORTC &= ~(1<<4); PORTA &= ~(1<<0); PORTA &= ~(1<<1); PORTA &= ~(1<<2); PORTA &= ~(1<<3); break;
			case 1 : PORTC &= ~(1<<7); PORTC |=  (1<<6); PORTC &= ~(1<<5); PORTC &= ~(1<<4); PORTA &= ~(1<<0); PORTA &= ~(1<<1); PORTA &= ~(1<<2); PORTA &= ~(1<<3); break;
			case 2 : PORTC &= ~(1<<7); PORTC &= ~(1<<6); PORTC |=  (1<<5); PORTC &= ~(1<<4); PORTA &= ~(1<<0); PORTA &= ~(1<<1); PORTA &= ~(1<<2); PORTA &= ~(1<<3); break;
			case 3 : PORTC &= ~(1<<7); PORTC &= ~(1<<6); PORTC &= ~(1<<5); PORTC |=  (1<<4); PORTA &= ~(1<<0); PORTA &= ~(1<<1); PORTA &= ~(1<<2); PORTA &= ~(1<<3); break;
			case 4 : PORTC &= ~(1<<7); PORTC &= ~(1<<6); PORTC &= ~(1<<5); PORTC &= ~(1<<4); PORTA |=  (1<<0); PORTA &= ~(1<<1); PORTA &= ~(1<<2); PORTA &= ~(1<<3); break;
			case 5 : PORTC &= ~(1<<7); PORTC &= ~(1<<6); PORTC &= ~(1<<5); PORTC &= ~(1<<4); PORTA &= ~(1<<0); PORTA |=  (1<<1); PORTA &= ~(1<<2); PORTA &= ~(1<<3); break;
			case 6 : PORTC &= ~(1<<7); PORTC &= ~(1<<6); PORTC &= ~(1<<5); PORTC &= ~(1<<4); PORTA &= ~(1<<0); PORTA &= ~(1<<1); PORTA |=  (1<<2); PORTA &= ~(1<<3); break;
			case 7 : PORTC &= ~(1<<7); PORTC &= ~(1<<6); PORTC &= ~(1<<5); PORTC &= ~(1<<4); PORTA &= ~(1<<0); PORTA &= ~(1<<1); PORTA &= ~(1<<2); PORTA |=  (1<<3); break;
			}
			_delay_ms(1);						// 1ms delay between each line = multiplexing at 1/(8*0.001s) = 125Hz
		}
		// 8ms passed, do it again 1250 times to display for 10s
	}
	PORTC &= ~(1<<7); PORTC &= ~(1<<6); PORTC &= ~(1<<5); PORTC &= ~(1<<4); PORTA &= ~(1<<0); PORTA &= ~(1<<1); PORTA &= ~(1<<2); PORTA &= ~(1<<3); // Display is OFF
	PORTB &= 0b11100000;						// Display is OFF
	PORTA &= 0b10001111;						// Display is OFF
}

void sleep()
{
	PORTD |= (1<<PD4);							// Turn OFF LED on PD4 (output 5v to LED cathode)
	
	ACSR |= (1<<ACD);          					// Disable Analog comparator	
	
	GICR |= (1<<INT1);							// Enable interrupt	INT1
	MCUCR &= ~((1<<ISC11) | (1<<ISC10));		// Enable interrupt on low level of INT1 (only compatible mode with sleep mode wake up on INT1)
	
	set_sleep_mode(SLEEP_MODE_PWR_DOWN);   	 	// Set sleep mode to "power down mode"
	sleep_enable();                        		// Sets the Sleep Enable bit in the MCUCR Register (SE BIT)
	sei();                                 		// Enable interrupts
	sleep_cpu();                           		// sleep

	//...Wait for interrupt to wake-up MCU...
	
	// Interruption occurred : ISR(INT1_vect) is called
	
	cli();                                  	// Disable interrupts
	sleep_disable();                        	// Clear Sleep Enable bit (SE bit)
}

ISR(INT1_vect)									// Interrupt service routine
{
	if (setmode)								// If user is changing the time
	{
		time_counter=0;							// Reset time counter, allowing 5 more seconds to change the time before returning to sleep mode
		bt_flag = 1;							// Set button flag to 1, to change time
	} 
	else										// If the interruption occurred during sleep mode
	{
		sleep_disable();						// When interruption occurred, disable sleep mode (and so wake MCU up)
	}
}

void io_setup()
{
	DDRA = 0x7F;								// PORTA as output except PA7 as input
	DDRB = 0xFF;								// PORTB as output
	DDRC = 0xFC;								// PORTC as output
	DDRD = 0x14;								// PD3 as input, PD4 and PD2 as outputs
	
	PORTA = 0x00;								// All outputs low
	PORTB = 0x00;								// All outputs low
	PORTC = 0x00;								// All outputs low
	PORTD = 0x10;								// All outputs low except PD4 (led OFF)
	PORTD |= (1<<PD3);							// Enable pullup on PD3
}

void check_battery(uint8_t *lowbat, uint8_t *critbat)
{
	float adcvalue, voltage;					// Variables declaration
	
	ADMUX = 0x47;								// Select ADC7 and reference voltage on AVCC (with capacitor to GND at AREF pin)
	ADCSRA |= (1<<ADPS1) | (1<<ADPS0);			// ADC clock prescaler /8
	ADCSRA |= (1<<ADEN);						// Enable ADC
	ADCSRA |= (1<<ADSC);						// Start ADC conversion
	loop_until_bit_is_clear(ADCSRA, ADSC); 		// Wait until done
	adcvalue = ADC;								// Read ADC
	ADCSRA &= ~(1<<ADEN);      					// Disable ADC
	
	voltage = adcvalue*3.3*43/1023/33;			// Actual battery voltage
	
	if(voltage < V_LOWBAT) *lowbat = 1;			// If battery level is low, rise a corresponding flag
	else *lowbat = 0;
	
	if(voltage < V_CRITBAT) *critbat = 1;		// If battery level is critical, rise a corresponding flag
	else *critbat = 0;
}

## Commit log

2017-04-30 Add files via upload
    Add schematics and board files (Eagle format)
    [Word Clock.brd, Word Clock.sch]
2017-04-30 Update Eagle files
    [Word Clock.sch]
2017-05-01 Add files via upload
    PCB print files, ready to print and transfer on PCB.
    TOP is mirrored, BOTTOM is not
2017-05-01 Clean silkscreen
    [Word Clock.brd]
2017-10-29 Add a time-set function
    Long press (10s) on the button make the device enter time-set mode. You no longer require to reflash firmware to set the time.
    [main.c]

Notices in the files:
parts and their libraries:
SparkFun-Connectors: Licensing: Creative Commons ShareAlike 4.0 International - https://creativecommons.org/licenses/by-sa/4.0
